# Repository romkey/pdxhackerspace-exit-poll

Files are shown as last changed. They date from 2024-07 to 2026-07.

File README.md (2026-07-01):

# PDX Hackerspace Exit Poll

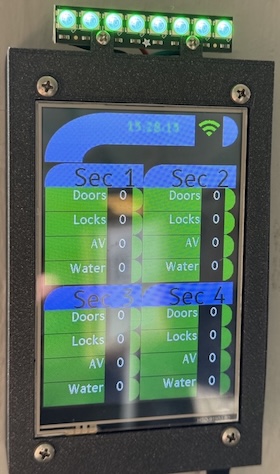
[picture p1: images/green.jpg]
All good
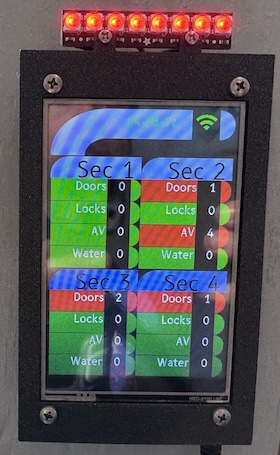
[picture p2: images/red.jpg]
Attention!


Exit Poll is a display that integrates with Home Assistant that lets you know about things that might need attention.

At PDX Hackerspace, the last person out should check on the physical
security of the space and turn off certain equipment that may be on.
Member Kenny M had the idea of placing an electronic dashboard next to
the door so that departing members could quickly see if anything
needed attention.

We use Home Assistant to automate the space. Exit Poll uses Home
Assistant data to display counts of open doors, unlocked doors,
running water and AV equipment, all of which might need attention from
the last person to leave the space.

## Firmware

We build the firmware for this project using
[ESPHome](https://esphome.io). ESPHome is great for projects that are
tightly integrated with Home Assistant. As Home Assistant runs all our
security-related sensors, it's a good choice for us.

```
substitutions:
  name: "exit-poll"
  friendly_name: "Exit Poll"
  led_chip: "WS2812"
  led_order: "GRB"
  led_number: "8"
  display_model: "ILI9488"

packages:
  exit-poll:
    url: https://github.com/romkey/pdxhackerspace-exit-poll
    files: [esphome/exit-poll.yml, esphome/tinys3.yml]
    ref: main
    refresh: 1s

api:
  encryption:
    key: "YOUR API KEY"

ota:
  platform: esphome
  password: "YOUR OTA PASSWORD"

wifi:
  ssid: !secret wifi_ssid
  password: !secret wifi_password
#  use_address: w.x.y.z

  ap:
    ssid: "PDX Hackerspace Exit Poll Fallback Hotspot"
    password: "YOUR HOTSPOT PASSWORD"
```

## Docker

The repo includes a Docker compose file that will bring up ESPHome for building and deploying the firmware.

You'll need Docker and the compose plugin installed on your system.

To run:

```
docker compose up
```

## Hardware

We use cheap a 320x480 SPI TFT display connected to Unexpected Maker's
TinyS3 board on a custom PCB, but you can use virtually any ESP32
board that's fast enough with enough storage and RAM for your needs
that you solder together. We use displays with touch support - the PCB
wires the touch pins to the CPU but the firmware currently does not
take advantage of it.

If you want to use a different resolution display you'll of course
need to rewrite the code which puts information on the display.

The PCB is available at [OSHPark](https://oshpark.com/shared_projects/85wfS3FQ).

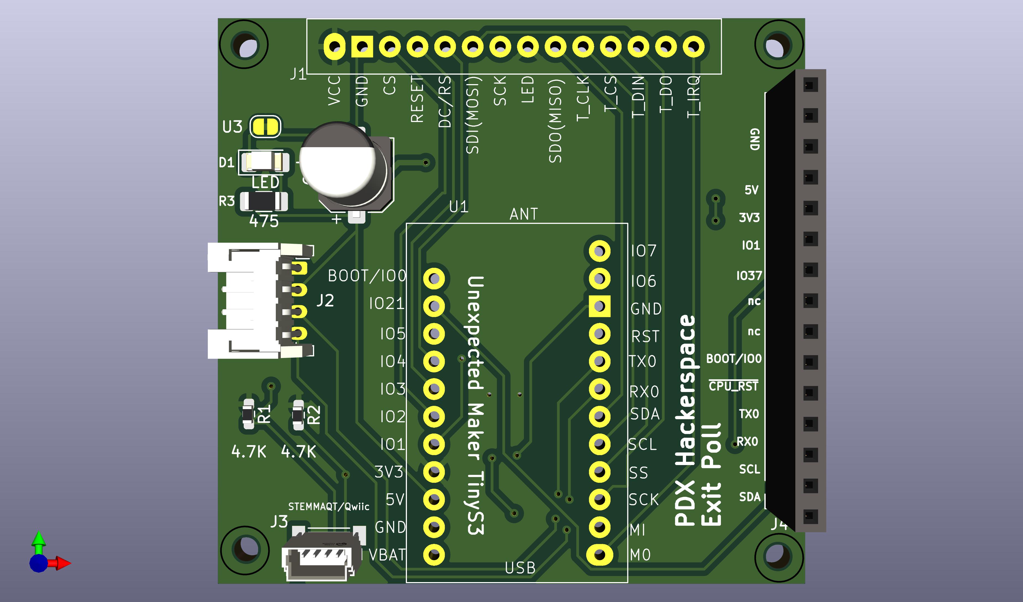
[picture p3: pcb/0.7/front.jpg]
PCB front
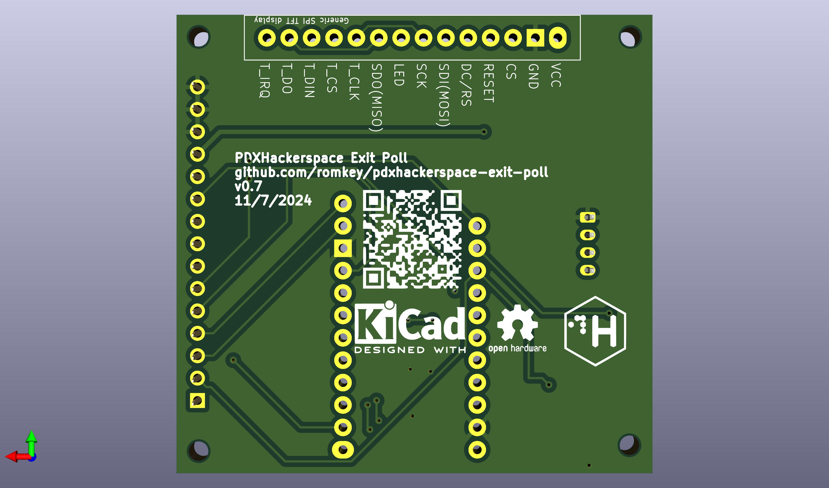
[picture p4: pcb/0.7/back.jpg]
PCB back


### Assembly

Most of the components on the board are optional.

C1 is entirely optional. It's intended to smooth power to the LED
strip, if you use one. In practice with just a few LEDs it's
unnecessary. We will probably drop it if we update the PCB again.

If you don't want the power indicator, omit D1 and R3.

If you don't want external I2C support via the Qwiic/Stemma QT
connector, omit R1, R2 and J3.

Although the board shows a female header strip for the connections on
the right hand side, ignore it if you're not using those for expansion
or wire them however is convenient for you if you are. You might for
instance wire in buttons for reset and programming (BOOT).

The bare minimum assembly is to solder the TinyS3 to the front of PCB
and then solder the display to the back. Be sure that the pinout of
the display you're using matches the pinout of the holes for its
pins. If it doesn't, you'll need to figure out how to wire it.

## Case

The repo includes [OpenSCAD files](https://openscad.org) for a minimal
case for a 4" display that mounts the display on a frame the snaps
into a box that can be mounted on a wall, with a hole in the bottom
for the USB power cable. If you use a different size display you will
of course need to redesign the case. It also includes the `.stl` file
for the case.

To print the case, load the `.stl` file into the slicer you use with
your 3D printer and follow your printer's instructions to slice and
print the case. PLA and PETG are good materials for the case.

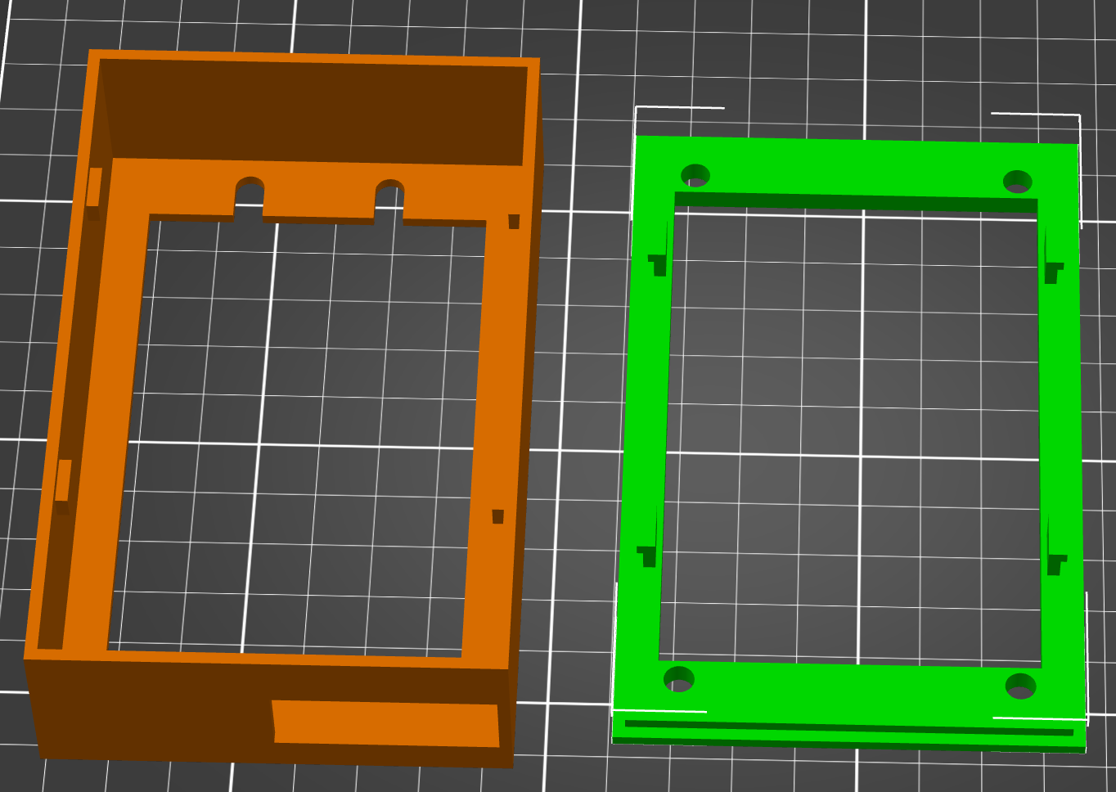
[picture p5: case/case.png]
Case


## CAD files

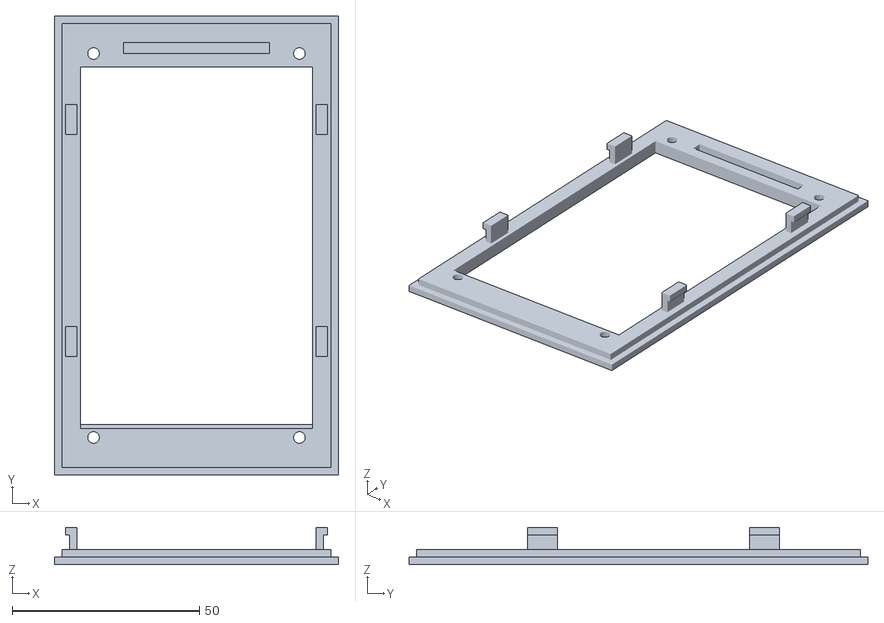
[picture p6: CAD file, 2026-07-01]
case/cover.stl
75.7 x 122.4 x 10.0

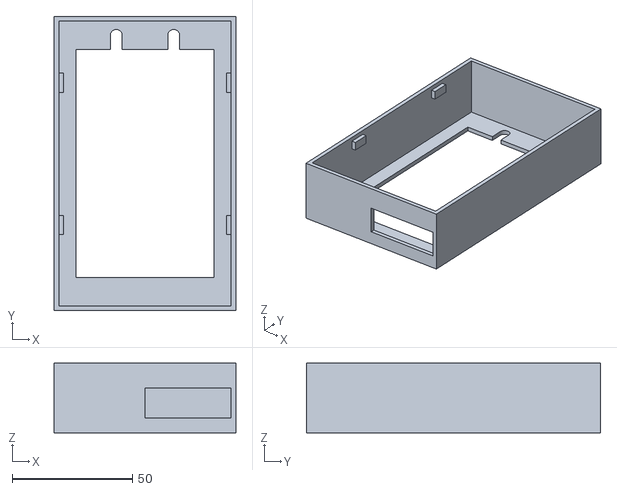
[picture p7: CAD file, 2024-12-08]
case/box.stl
75.7 x 122.4 x 29.0

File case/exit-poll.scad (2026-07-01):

// PDX Hackerspace Exit Poll
// https://www.aliexpress.us/item/3256802965763349.html
// https://www.aliexpress.us/item/3256804835346770.html
$fn = 60;

render_stl = 0;
// 3.5"
// display_width = 56;
// display_height = 98;

// 4.0"
display_width = 61.74;
display_height = 108.4;

hole_radius = 1.55; //For a diameter of 3.1, 3mm+clearance for an M3 Screw
hole_width_offset = 3.42;
hole_height_offset = 3;

bottom_margin = 6.5;
top_margin = 6.54;


// "active area" 48.96x73.44(mm)
//active_width = 48.96;
//active_height = 73.44;

led_width = display_width;
led_height = display_height - bottom_margin - top_margin;

case_width = display_width + 10;
case_height = display_height + 10;
case_depth = 25;

thickness = 2;

screw_hole_diameter = 5/32*25.4 + 1;;

catch_height = 4;
catch_width = 8;

usb_cutout_width = 20;
usb_cutout_height = 8;

module catch() {
    cube([thickness, catch_width, catch_height]);
    translate([-1, 0, catch_height])
      cube([thickness + 1, catch_width, 2]);
}

module cover() {
difference() {
    union() {
      cube([case_width, case_height, thickness*2]);
      translate([-thickness, -thickness, 0])
        cube([case_width + thickness*2, case_height + thickness*2, thickness]);
      }
    //Cut hole for display
    translate([(case_width - led_width)/2, bottom_margin+5, -1])
      cube([led_width, led_height, thickness*2+2]);
    //Screw Holes
    translate([5 + hole_width_offset, 5 + hole_height_offset, 0])
      cylinder(h = thickness*2, r = hole_radius);
    translate([5 + hole_width_offset, case_height - (5 + hole_height_offset), 0])
      cylinder(h = thickness*2, r = hole_radius);
    translate([case_width - (5 + hole_width_offset), 5 + hole_height_offset, 0])
      cylinder(h = thickness*2, r = hole_radius);
    translate([case_width - (5 + hole_width_offset), case_height - (5 + hole_height_offset), 0])
      cylinder(h = thickness*2, r = hole_radius);
    
      //Cut out a slot for the touchscreen header pins to sit in
      top_to_center_pin_distance = 6.5;
      
      translate([case_width/2, case_height-         top_to_center_pin_distance, (thickness*2)-0.5]){
        cube([39,3,3],true);
      }
      
      //Add a lip at the bottom to keep from stressing the display to pcb connection
      translate([case_width/2, bottom_margin+5, thickness]){
          rotate([30,0,0]) translate([0,1,thickness*2])
            cube([led_width, 2, thickness*4],true);
      }
  }
  
  
  module left_side_catches(){
      translate([thickness, case_height/4, thickness*2]) {
          catch();
      }
      translate([thickness, 3*case_height/4, thickness*2]) {
          catch();
      }
  }
  
  //Build the left side
  left_side_catches();
  
  //Then the right (with mirroring)
  translate([case_width, 0,0]) mirror([1,0,0]) {
     left_side_catches();
  }
}

module box() {
    difference() {
      cube([case_width + thickness*2, case_height+thickness*2, case_depth+thickness*2]);

      translate([thickness, thickness, thickness])
        cube([case_width, case_height, case_depth + thickness]);
      translate([thickness + case_width/10, thickness + case_height/10, 0])
        cube([8*case_width/10, 8*case_height/10, thickness]);

      translate([thickness + case_width/3, thickness + case_height*19/20, 0])
        cylinder(h = thickness*2, d = screw_hole_diameter);

      translate([thickness + case_width/3 - screw_hole_diameter/2, thickness + case_height*18/20, 0])
        cube([screw_hole_diameter, case_height/20, thickness]);

      translate([thickness + 2*case_width/3, thickness + case_height*19/20, 0])
        cylinder(h = thickness*2, d = screw_hole_diameter);
      translate([thickness + 2*case_width/3 - screw_hole_diameter/2, thickness + case_height*18/20, 0])
        cube([screw_hole_diameter, case_height/20, thickness]);
        
      translate([(case_width + thickness*2 - usb_cutout_width)/2, 0, case_depth/4])
        cube([usb_cutout_width, thickness, usb_cutout_height]);
    }

    translate([thickness, thickness + case_height/4, thickness+case_depth-catch_height])
      cube([thickness, catch_width, catch_height]);
     translate([thickness, thickness + 3*case_height/4, thickness+case_depth-catch_height])
      cube([thickness, catch_width, catch_height]); 
    translate([case_width, thickness + case_height/4, thickness+case_depth-catch_height])
      cube([thickness, catch_width, catch_height]);
     translate([case_width, thickness + 3*case_height/4, thickness+case_depth-catch_height])
      cube([thickness, catch_width, catch_height]); 
}

module box_big_notch() {
    difference() {
      cube([case_width + thickness*2, case_height+thickness*2, case_depth+thickness*2]);

      // hollow out the inside of the box
      translate([thickness, thickness, thickness])
        cube([case_width, case_height, case_depth + thickness]);

      // save filament by cutting out most of the back panel
      translate([thickness + case_width/10, thickness + case_height/10, 0])
        cube([8*case_width/10, 8*case_height/10, thickness]);

      // knockouts for hanging the box on screws
      translate([thickness + case_width/3, thickness + case_height*19/20, 0])
        cylinder(h = thickness*2, d = screw_hole_diameter);
      translate([thickness + case_width/3 - screw_hole_diameter/2, thickness + case_height*18/20, 0])
        cube([screw_hole_diameter, case_height/20, thickness]);
      translate([thickness + 2*case_width/3, thickness + case_height*19/20, 0])
        cylinder(h = thickness*2, d = screw_hole_diameter);
      translate([thickness + 2*case_width/3 - screw_hole_diameter/2, thickness + case_height*18/20, 0])
        cube([screw_hole_diameter, case_height/20, thickness]);
        
      // USB cable knockout
      translate([(case_width + thickness*2)/2, 0, case_depth/4])
        cube([case_width/2, thickness, case_depth/2]);

      // knockout for LED cables
//      translate([(case_width- 10 + thickness)/2, case_height+thickness, case_depth + thickness*2 - 10])
//        cube([10, thickness, 10]);
    }

    translate([thickness, thickness + case_height/4, thickness+case_depth-catch_height])
      cube([thickness, catch_width, catch_height]);
     translate([thickness, thickness + 3*case_height/4, thickness+case_depth-catch_height])
      cube([thickness, catch_width, catch_height]); 
    translate([case_width, thickness + case_height/4, thickness+case_depth-catch_height])
      cube([thickness, catch_width, catch_height]);
     translate([case_width, thickness + 3*case_height/4, thickness+case_depth-catch_height])
      cube([thickness, catch_width, catch_height]); 
}

module base() {
    d = case_height + thickness*4;
    translate([d*.5/4, d*1.5/3, 0])
      linear_extrude(thickness) {
        scale([.5, 1.5])
          circle(d = d);
    }    

  translate([0, 0, thickness])
  difference() {
    cube([case_depth + thickness*5, case_height + thickness*4, 7]);
    translate([thickness, thickness, 0])
      cube([case_depth + thickness*3, case_height + thickness*2, 7]);
  }
}


// Render the case and box side by side about origin for easy viewing
module main(){
    translate([-(case_width*1.2), 0, 0]){
        box_big_notch();
    }

    translate([(case_width*0.2), 0, 0]){
        cover();
    }
}

//Hack to render a specific part
// Use openscad -D render_stl=# -o <outfile> exit-poll.scad to render a specific part
if(render_stl==0)
    main();
if(render_stl==1)
    box_big_notch();
if(render_stl==2)
    cover();

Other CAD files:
case/face.stl
case/exit-poll-4in.stl

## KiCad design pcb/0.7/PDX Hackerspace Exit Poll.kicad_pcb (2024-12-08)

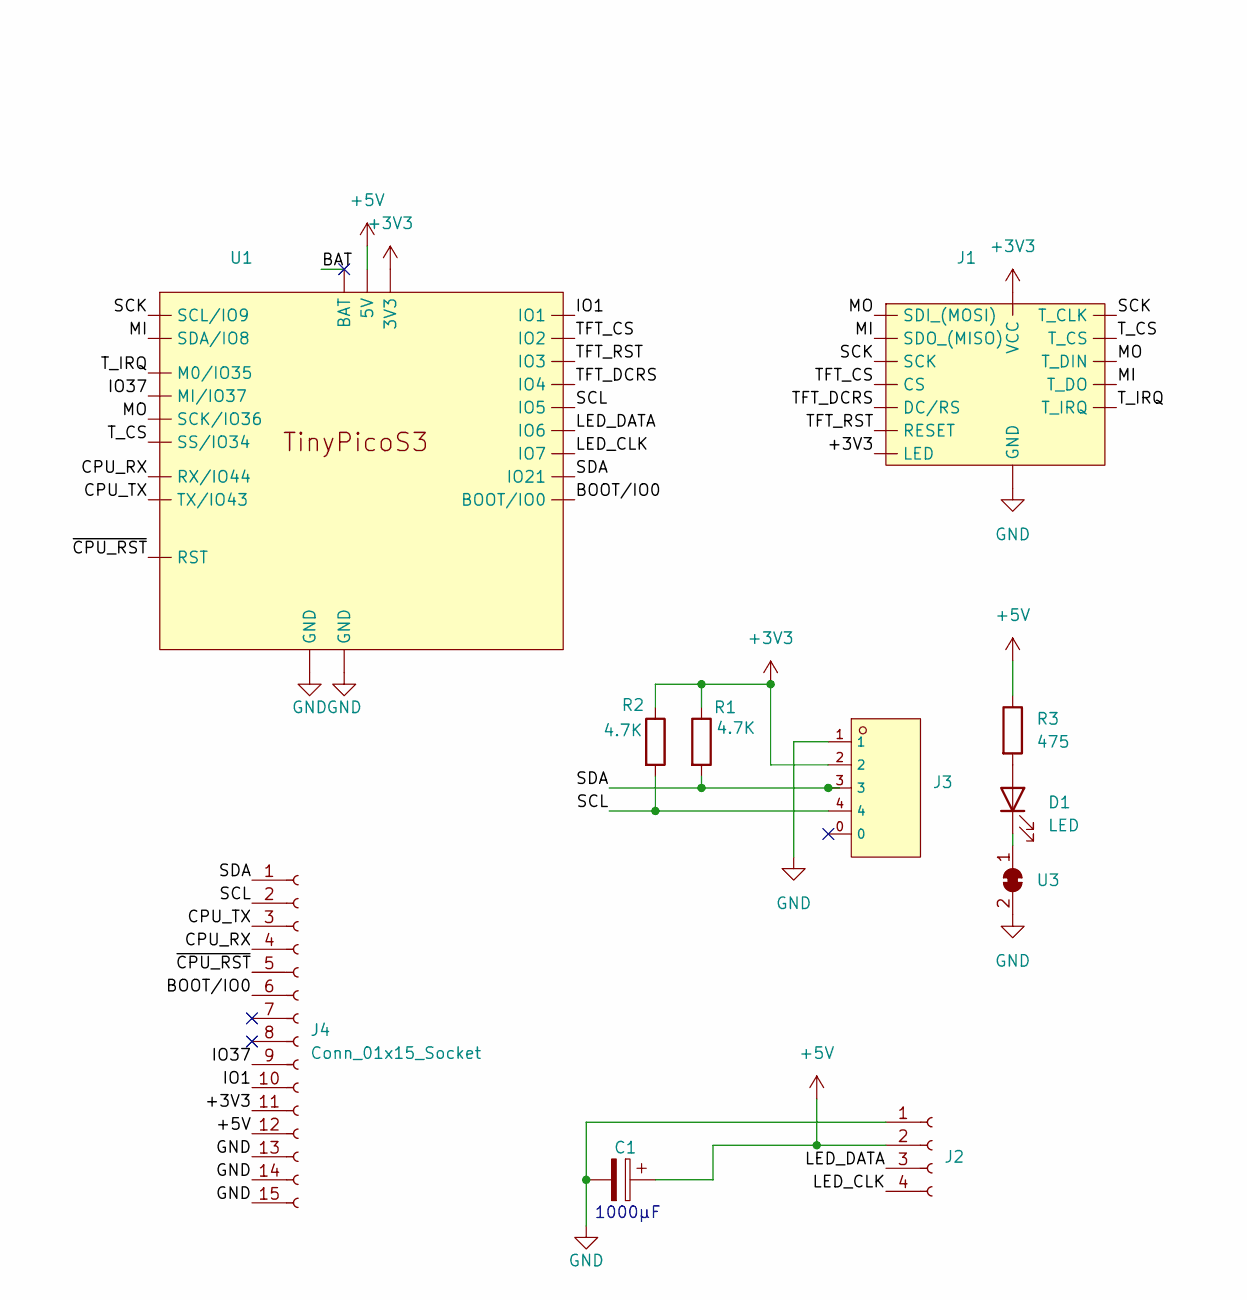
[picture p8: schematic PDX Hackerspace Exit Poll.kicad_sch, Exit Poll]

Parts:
C1: 100µF; CP_Elec_6.3x7.7; MPN C72477
D1: LED; LED_1206_3216Metric_Pad1.42x1.75mm_HandSolder; MPN C28310439
J1: SPI_TFT_TOUCH
J2: Conn_01x04_Socket; JST_PH_S4B-PH-K_1x04_P2.00mm_Horizontal; MPN C160235
J3: CONN-SMD_BM04B-SRSS-TB; MPN C160390; LCSC C160390
J4: Conn_01x15_Socket; PinSocket_1x15_P2.54mm_Vertical
R1, R2: 4.7K; R_0603_1608Metric_Pad0.98x0.95mm_HandSolder; MPN C4355002
R3: 475; R_1206_3216Metric_Pad1.30x1.75mm_HandSolder; MPN C323067
U1: TinyS3
U3: SolderJumper-2_P1.3mm_Bridged_RoundedPad1.0x1.5mm

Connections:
+3V3: J1.1 (VCC), J1.8 (LED), J3.2, J4.11, R1.1, R2.1, U1.20 (3V3)
+5V: C1.1, J2.2, J4.12, R3.1, U1.21 (5V)
/BAT: U1.23 (BAT)
/BOOT/IO0: J4.6, U1.13 (BOOT/IO0)
/CPU_RX: J4.4, U1.12 (RX/IO44)
/CPU_TX: J4.3, U1.11 (TX/IO43)
/IO1: J4.10, U1.19 (IO1)
/IO37: J4.9, U1.2 (MI/IO37)
/LED_CLK: J2.4, U1.7 (IO7)
/LED_DATA: J2.3, U1.8 (IO6)
/MI: J1.9 (SDO_(MISO)), J1.13 (T_DO), U1.6 (SDA/IO8)
/MO: J1.6 (SDI_(MOSI)), J1.12 (T_DIN), U1.3 (SCK/IO36)
/SCK: J1.7 (SCK), J1.10 (T_CLK), U1.5 (SCL/IO9)
/SCL: J3.4, J4.2, R2.2, U1.15 (IO5)
/SDA: J3.3, J4.1, R1.2, U1.14 (IO21)
/TFT_CS: J1.3 (CS), U1.18 (IO2)
/TFT_DCRS: J1.5 (DC/RS), U1.16 (IO4)
/TFT_RST: J1.4 (RESET), U1.17 (IO3)
/T_CS: J1.11 (T_CS), U1.4 (SS/IO34)
/T_IRQ: J1.14 (T_IRQ), U1.1 (M0/IO35)
/~CPU_RST: J4.5, U1.9 (RST)
GND: C1.2, J1.2 (GND), J2.1, J3.1, J4.13, J4.14, J4.15, U1.10 (GND), U1.22 (GND), U3.2 (B)
unnamed: D1.2 (A), R3.2
unnamed: D1.1 (K), U3.1 (A)

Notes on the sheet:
1000µF

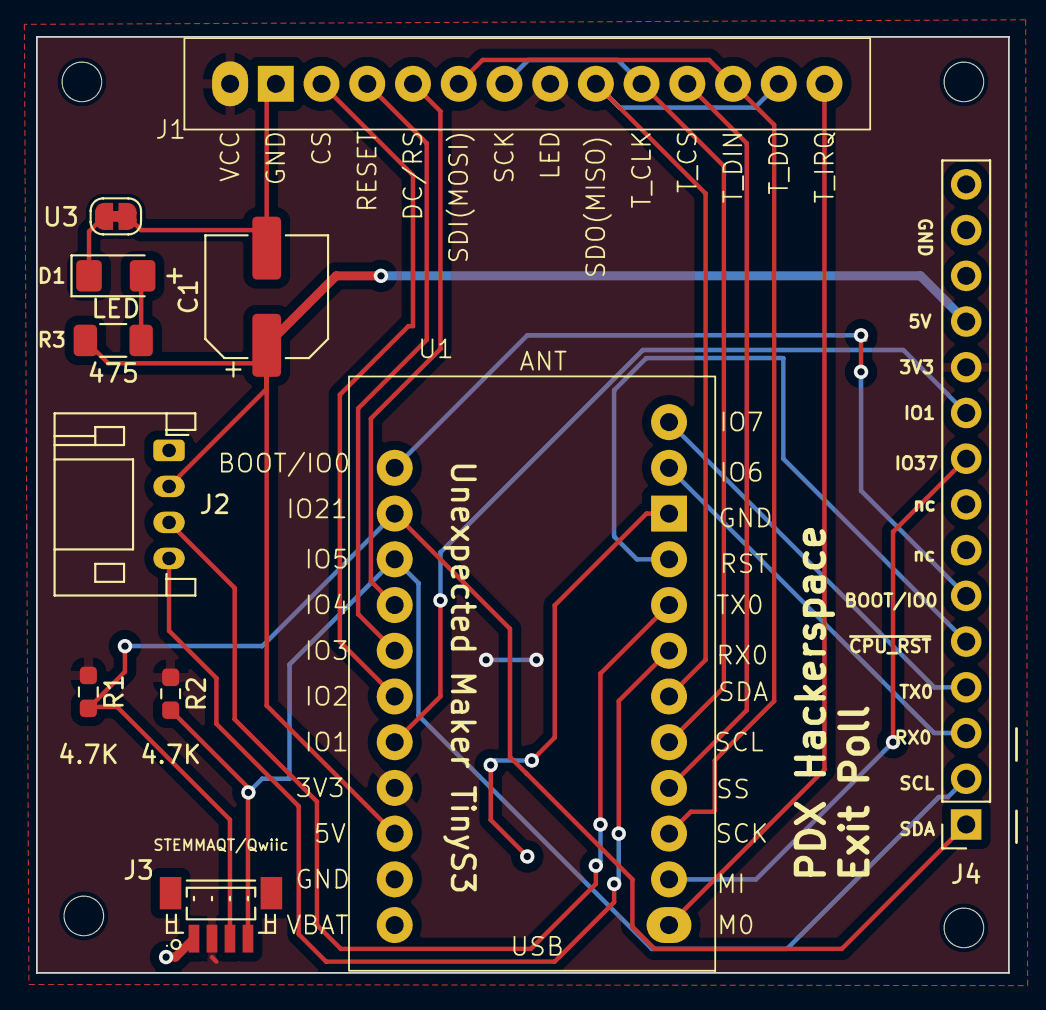
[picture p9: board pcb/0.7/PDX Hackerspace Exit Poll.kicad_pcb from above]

Board: 2 copper layers, 54.0 x 52.0 mm, 12 parts (1 on the bottom side), 23 nets.

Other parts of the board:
G**: LOGO

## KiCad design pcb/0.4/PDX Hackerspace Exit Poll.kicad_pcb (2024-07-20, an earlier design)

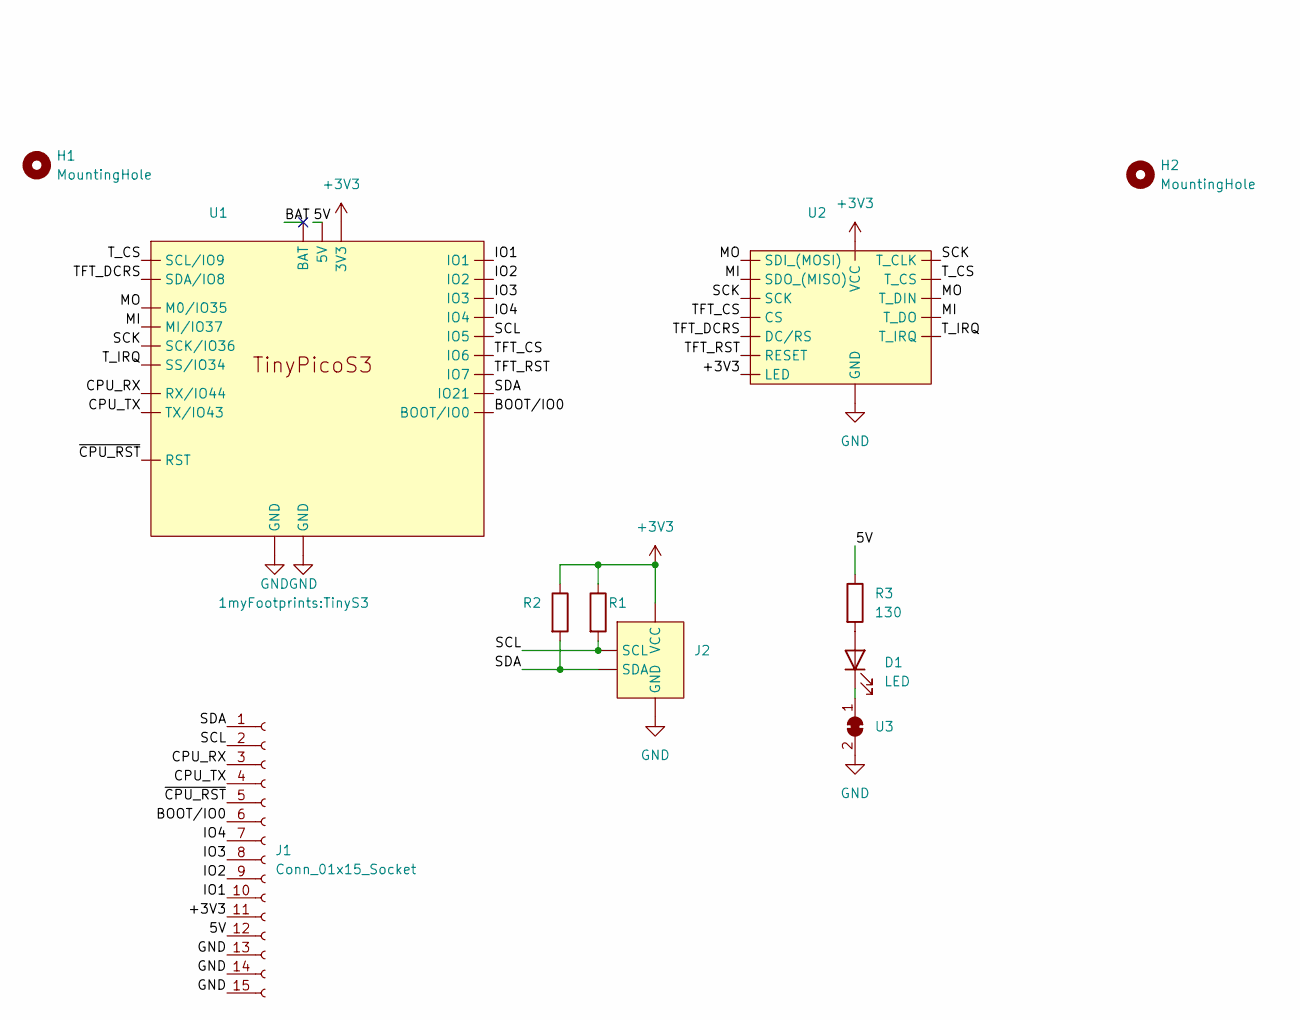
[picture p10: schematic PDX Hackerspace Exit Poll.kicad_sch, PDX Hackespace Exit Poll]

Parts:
D1: LED; LED_1206_3216Metric_Pad1.42x1.75mm_HandSolder
H1, H2: MountingHole; MountingHole_2.7mm_M2.5
J1: Conn_01x15_Socket; PinSocket_1x15_P2.54mm_Vertical
J2: JST_SH_SM04B-SRSS-TB_1x04-1MP_P1.00mm_Horizontal
R1, R2: 4.7K; R_Axial_DIN0204_L3.6mm_D1.6mm_P5.08mm_Horizontal
R3: 130; R_1206_3216Metric_Pad1.30x1.75mm_HandSolder
U1: TinyS3
U2: SPI_TFT_TOUCH
U3: SolderJumper-2_P1.3mm_Bridged_RoundedPad1.0x1.5mm

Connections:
+3V3: J1.11, J2.2 (VCC), R1.1, R2.1, U1.20 (3V3), U2.1 (VCC), U2.8 (LED)
/5V: J1.12, R3.1, U1.21 (5V)
/BAT: U1.23 (BAT)
/BOOT/IO0: J1.6, U1.13 (BOOT/IO0)
/CPU_RX: J1.3, U1.12 (RX/IO44)
/CPU_TX: J1.4, U1.11 (TX/IO43)
/IO1: J1.10, U1.19 (IO1)
/IO2: J1.9, U1.18 (IO2)
/IO3: J1.8, U1.17 (IO3)
/IO4: J1.7, U1.16 (IO4)
/MI: U1.2 (MI/IO37), U2.9 (SDO_(MISO)), U2.13 (T_DO)
/MO: U1.1 (M0/IO35), U2.6 (SDI_(MOSI)), U2.12 (T_DIN)
/SCK: U1.3 (SCK/IO36), U2.7 (SCK), U2.10 (T_CLK)
/SCL: J1.2, J2.4 (SCL), R1.2, U1.15 (IO5)
/SDA: J1.1, J2.3 (SDA), R2.2, U1.14 (IO21)
/TFT_CS: U1.8 (IO6), U2.3 (CS)
/TFT_DCRS: U1.6 (SDA/IO8), U2.5 (DC/RS)
/TFT_RST: U1.7 (IO7), U2.4 (RESET)
/T_CS: U1.5 (SCL/IO9), U2.11 (T_CS)
/T_IRQ: U1.4 (SS/IO34), U2.14 (T_IRQ)
/~CPU_RST: J1.5, U1.9 (RST)
GND: J1.13, J1.14, J1.15, J2.1 (GND), U1.10 (GND), U1.22 (GND), U2.2 (GND), U3.2 (B)
unnamed: D1.2 (A), R3.2
unnamed: D1.1 (K), U3.1 (A)

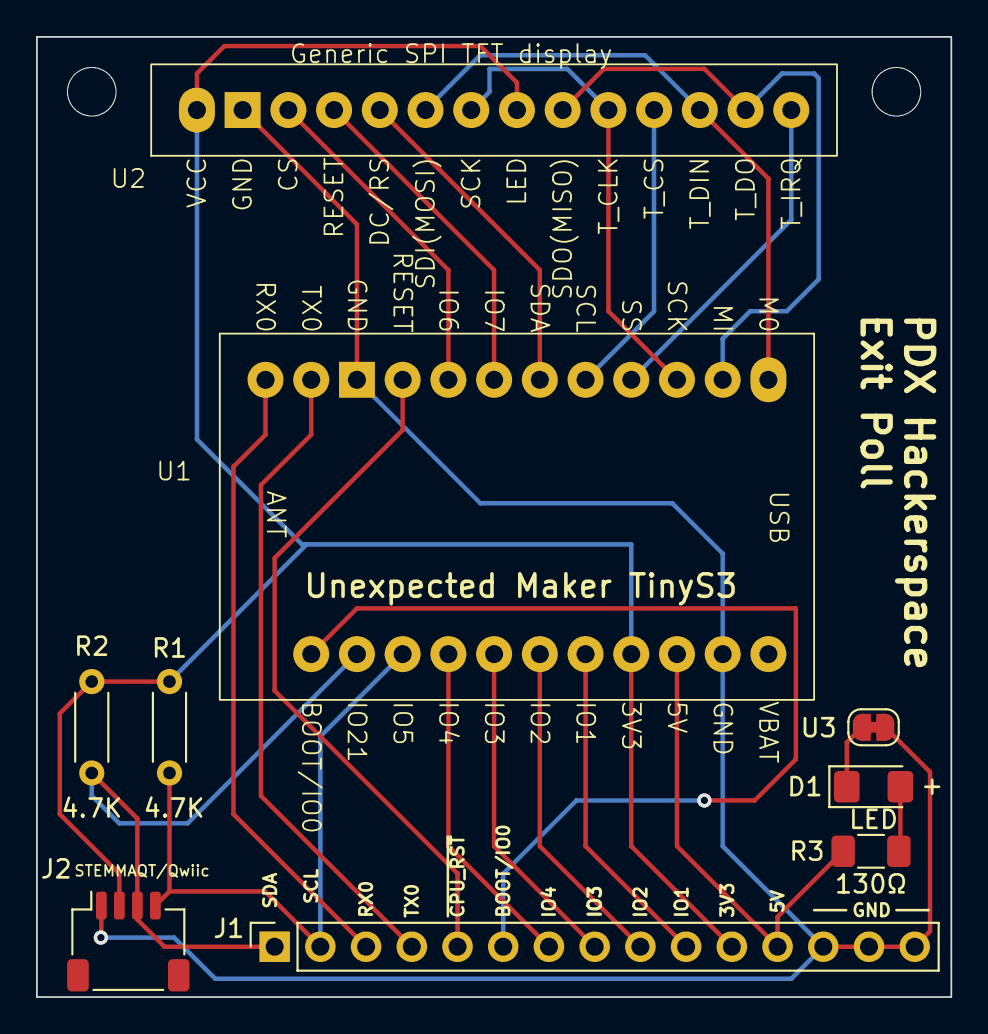
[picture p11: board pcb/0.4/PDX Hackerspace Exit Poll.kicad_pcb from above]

Board: 2 copper layers, 50.8 x 53.3 mm, 11 parts (0 on the bottom side), 23 nets.

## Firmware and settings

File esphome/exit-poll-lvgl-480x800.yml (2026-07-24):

# LCARS-styled LVGL UI for the exit-poll on the Guition 800x480 RGB panel, used
# in PORTRAIT (480 wide x 800 tall). LVGL owns the rotation (rotation: 90), which
# also rotates the touchscreen input, so the display component must NOT set a
# rotation.
#
# Look: black background, amber rounded header bar (title + clock + a black
# status "chip" holding the wifi / wireguard icons), four section panels each
# with a colored LCARS spine/tab (section number) and four rounded "pill" status
# bars (Doors / Locks / AV / Water), plus a decorative bottom accent bar. Bars
# are green when 0, red when >0, gray when unknown - mirroring the original LCARS
# display's semantics.
#
# ESPHome LVGL evaluates lambda/templated properties once at setup; the interval
# at the bottom calls lvgl.widget.refresh every second to re-evaluate the clock,
# status icons, bar colors and section counts.

lvgl:
  displays:
    - main_display
  touchscreens:
    - touchscreen_id: touch_gt911
  rotation: 90
  default_font: font_20pt
  bg_color: 0x000000

  style_definitions:
    - id: lcars_pill
      radius: 32
      pad_left: 18
      pad_right: 18
      border_width: 0
      bg_opa: COVER
    - id: lcars_tab
      radius: 14
      border_width: 0
      bg_opa: COVER
    - id: black_text
      text_font: font_20pt
      text_color: 0x000000

  pages:
    - id: main_page
      bg_color: 0x000000
      bg_opa: COVER
      pad_all: 0
      widgets:
        # ---------------- Header bar (amber LCARS elbow) ----------------
        - obj:
            align: TOP_MID
            y: 6
            width: 464
            height: 54
            radius: 27
            border_width: 0
            bg_color: 0xFF9900
            bg_opa: COVER
            pad_all: 0
            widgets:
              - label:
                  text: "EXIT POLL"
                  styles: black_text
                  align: LEFT_MID
                  x: 26
              - label:
                  id: lbl_time
                  styles: black_text
                  align: CENTER
                  text: !lambda |-
                    auto t = id(canonical_time).now();
                    if (!t.is_valid()) return std::string("--:--:--");
                    return t.strftime("%H:%M:%S");
              # Status chip: black rounded panel so the colored icons pop
              - obj:
                  align: RIGHT_MID
                  x: -8
                  width: 118
                  height: 40
                  radius: 20
                  border_width: 0
                  bg_color: 0x000000
                  bg_opa: COVER
                  pad_all: 0
                  widgets:
                    - label:
                        id: lbl_wg
                        align: LEFT_MID
                        x: 14
                        text_font: font_icons
                        text: !lambda |-
                          if (!id(wireguard_present)) return std::string("");
                          return std::string("\U0000E0DB");
                        text_color: !lambda |-
                          return id(wireguard_connected) ? lv_color_hex(0x00CC00)
                                                         : lv_color_hex(0xCC0000);
                    - label:
                        id: lbl_wifi
                        align: RIGHT_MID
                        x: -14
                        text_font: font_icons
                        text: !lambda |-
                          return id(wifi_id).is_connected() ? std::string("\U0000E63E")
                                                            : std::string("\U0000E648");
                        text_color: !lambda |-
                          return id(wifi_id).is_connected() ? lv_color_hex(0x00CC00)
                                                            : lv_color_hex(0xCC0000);
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

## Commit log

2024-12-08 KiCAD and image files for 0.7 pcb
    [PDX Hackerspace Exit Poll.kicad_pcb, PDX Hackerspace Exit Poll.kicad_sch]
2024-12-08 fixed a couple of substitution names
2024-12-08 moved led_number out of tinys3.yml
    updated README
2024-12-08 updated README
    added preview of case as well as updated OpenSCAD file
    [box.stl, exit-poll.scad, face.stl]
2024-12-09 finally include images of the actual device
2024-12-30 Starting to notate the scad file for easier feature detection
    [exit-poll.scad]
2024-12-30 Added slot to protect touchscreen pins, exported model for print test
    [cover.stl, exit-poll.scad]
2024-12-30 exported the wrong model, oops!
    [cover.stl, exit-poll.scad]
2024-12-31 Added a small cutout on the front cover to keep the display cable from getting smushed
    [cover.stl, exit-poll.scad]
2026-07-01 refactored, added Hosyond 4" CYD board support
2026-07-06 added support for Hosyond 4" CYD
    refactored to support multiple boards
    rewrote old appliance project and included that
2026-10-11 Split ESPHome configs into packages and per-board examples
    Board-independent logic moves to packages/ (exit-poll core, LEDs, LCARS SPI
    and LVGL screens, appliance sensors and screens) and every board's pins to
    examples/, so CI can build each board and other configs can reuse the
    packages. Shared networking moves to examples/common/base.yaml with
    encrypted OTA instead of a password, a password-protected web server and
    recovery buttons, as esphome-ai-coding-rules requires.
2026-10-11 Strip trailing whitespace from the case source
    Found by the new pre-commit whitespace hooks.
